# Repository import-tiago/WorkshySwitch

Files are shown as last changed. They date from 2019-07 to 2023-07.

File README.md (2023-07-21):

# WorkshySwitch
 

WorkshySwitch is an IoT device for wireless control of lamps without harming the use of the physical switch.

## Features
##### Controller Device / [SoC CC2541 with 8051 MCU and Embedded Bluetooth 4.0](http://www.ti.com/lit/ds/symlink/cc2541.pdf)

##### Wireless Technology / [Embedded Meandered Inverted F Antenna (MIFA) with 50 ohm at 2.45 GHz](https://github.com/import-tiago/WorkshySwitch/blob/master/Hardware/3.%20Datasheets/MCU/CC25XX%20-%20Small%20Size%202.4%20GHz%20PCB%20antenna.pdf)

##### Low Power Requirements / Does not apply in this project

##### Hardware Project / [Autodesk EAGLE](https://www.autodesk.com/products/eagle/free-download)

##### Firmware Project / [IAR Embedded Workbench](https://www.iar.com/iar-embedded-workbench/)

##### 3D Model Project / [Autodesk Fusion 360](https://www.autodesk.com/products/fusion-360/overview#banner)

## PCB Details
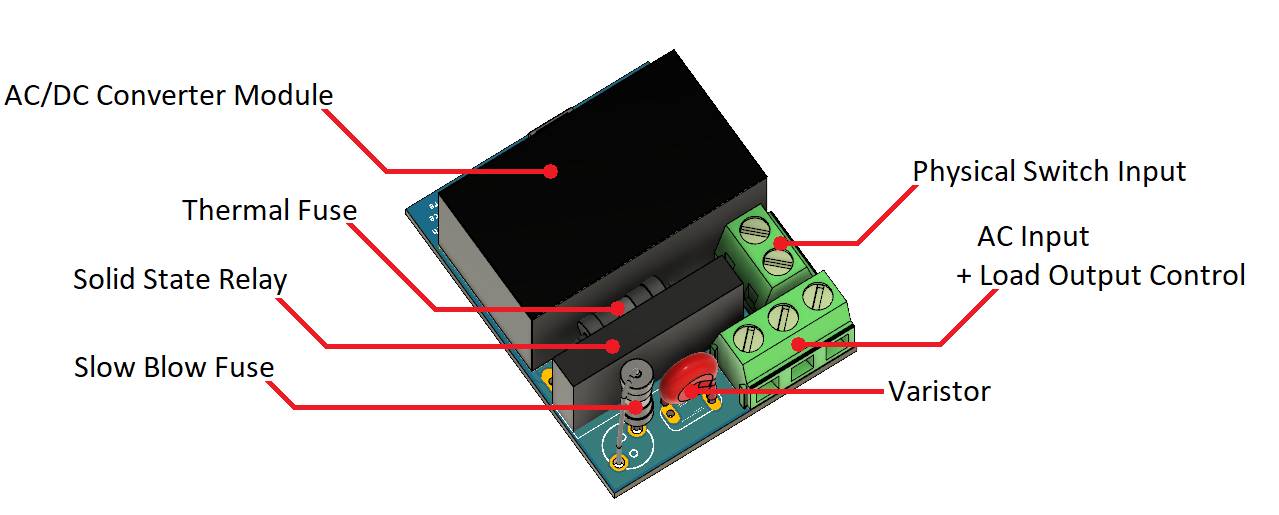
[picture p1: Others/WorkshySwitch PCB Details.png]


## How to Connect
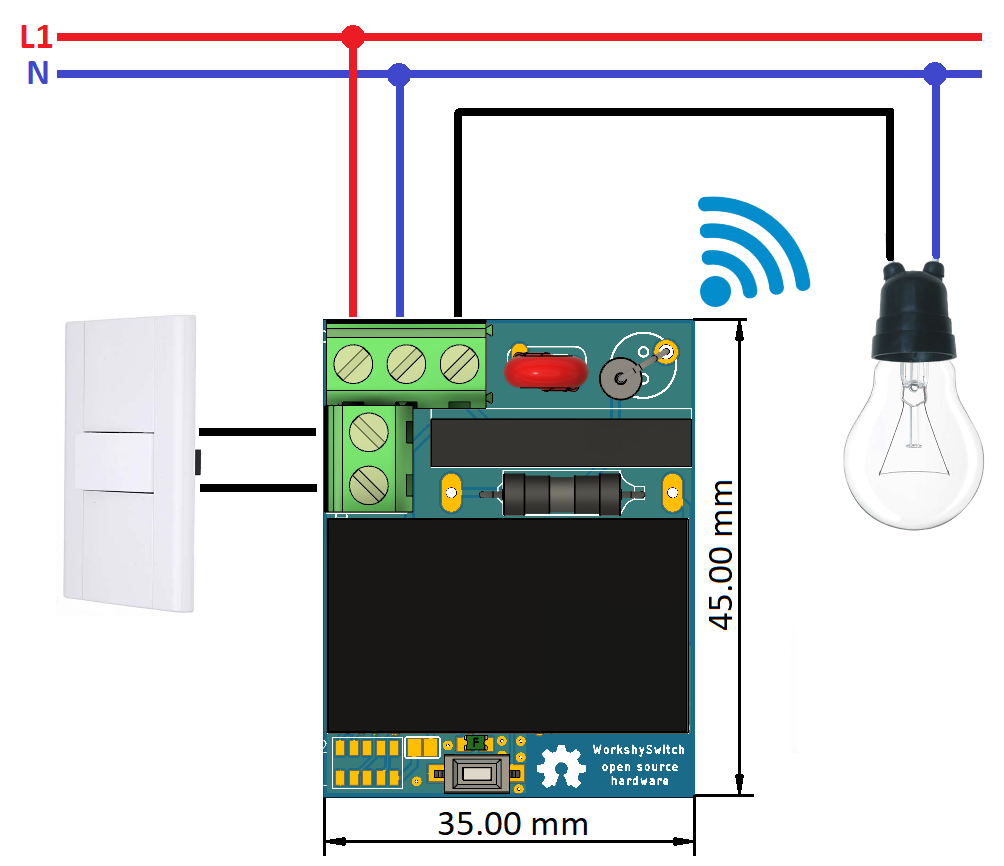
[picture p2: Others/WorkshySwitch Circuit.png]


## Schematic
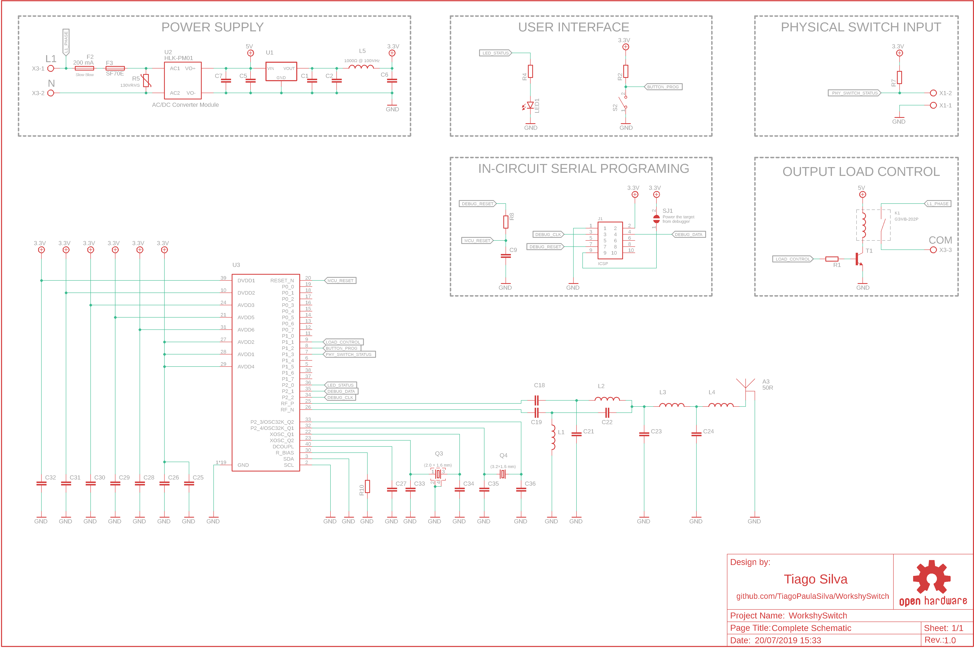
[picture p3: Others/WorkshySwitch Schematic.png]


### Contributing
0. Give this project a :star:
1. Create an issue and describe your idea.
2. [Fork it](https://github.com/import-tiago/WorkshySwitch/fork).
3. Create your feature branch (`git checkout -b my-new-feature`).
4. Commit your changes (`git commit -a -m "Added feature title"`).
5. Publish the branch (`git push origin my-new-feature`).
6. Create a new pull request.
7. Done! :heavy_check_mark:

### License Information
<br /><span xmlns:dct="http://purl.org/dc/terms/" property="dct:title">WorkshySwitch</span> by <a xmlns:cc="http://creativecommons.org/ns#" href="https://github.com/import-tiago" property="cc:attributionName" rel="cc:attributionURL">Tiago Silva</a> is licensed under a <a rel="license" href="http://creativecommons.org/licenses/by-sa/4.0/">Creative Commons Attribution-ShareAlike 4.0 International License</a>.<br />Permissions beyond the scope of this license may be available at <a xmlns:cc="http://creativecommons.org/ns#" href="https://twitter.com/import_tiago" rel="cc:morePermissions">tiagodepaulasilva@gmail.com</a>.

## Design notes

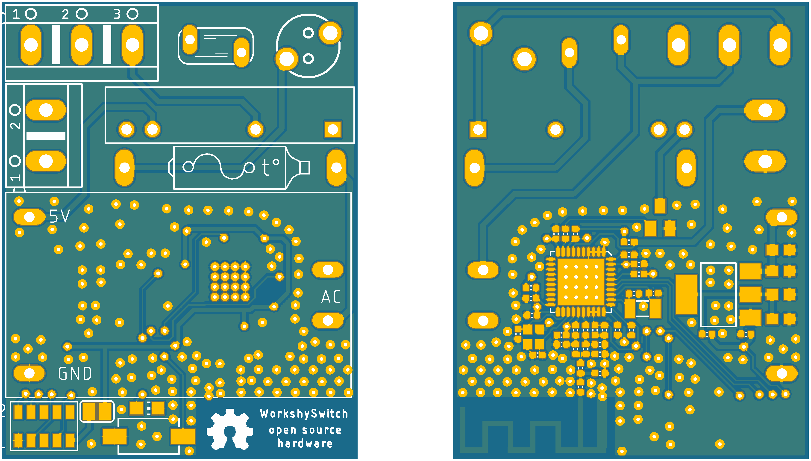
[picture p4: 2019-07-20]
Hardware/1. Mounting/WorkshySwitch.png

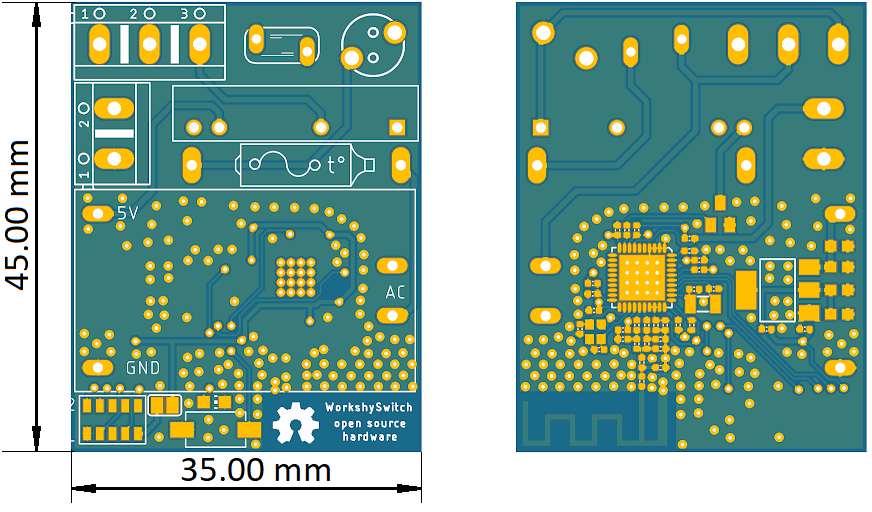
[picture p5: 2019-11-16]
Others/WorkshySwitch Gerber Preview.png

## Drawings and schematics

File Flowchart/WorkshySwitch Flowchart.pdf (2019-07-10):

# START

# WorkshySwitch MCU Firmware

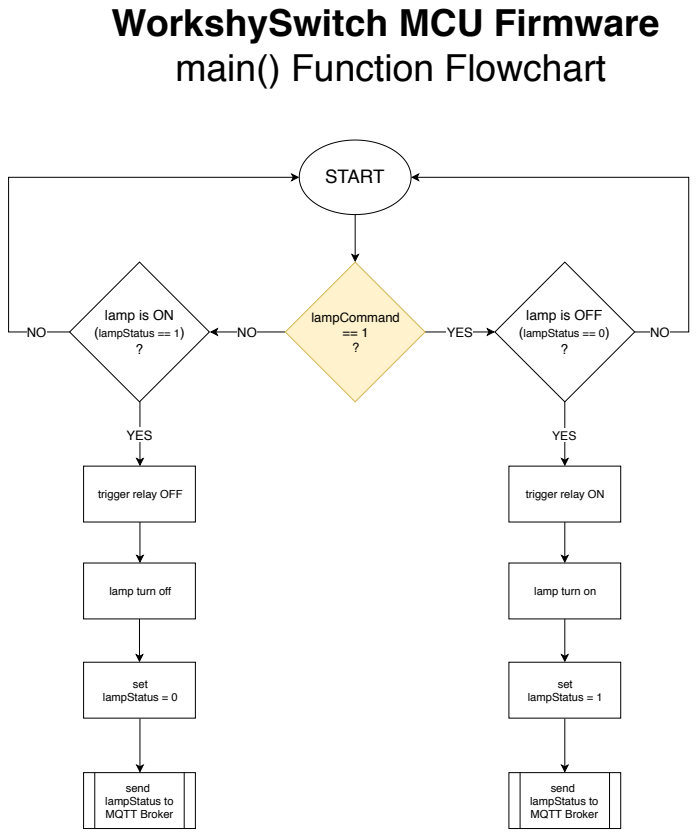
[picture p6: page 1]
set lampStatus = 1; send lampStatus to MQTT Broker; YES; lamp is OFF; (lampStatus == 0) ?; set lampStatus = 0; lamp is ON; (lampStatus == 1) ?; lampCommand == 1 ?

main() Function Flowchart

trigger relay OFF

trigger relay ON

lamp turn off

lamp turn on

# WorkshySwitch MCU Firmware Interrupt Services Routine Flowchart

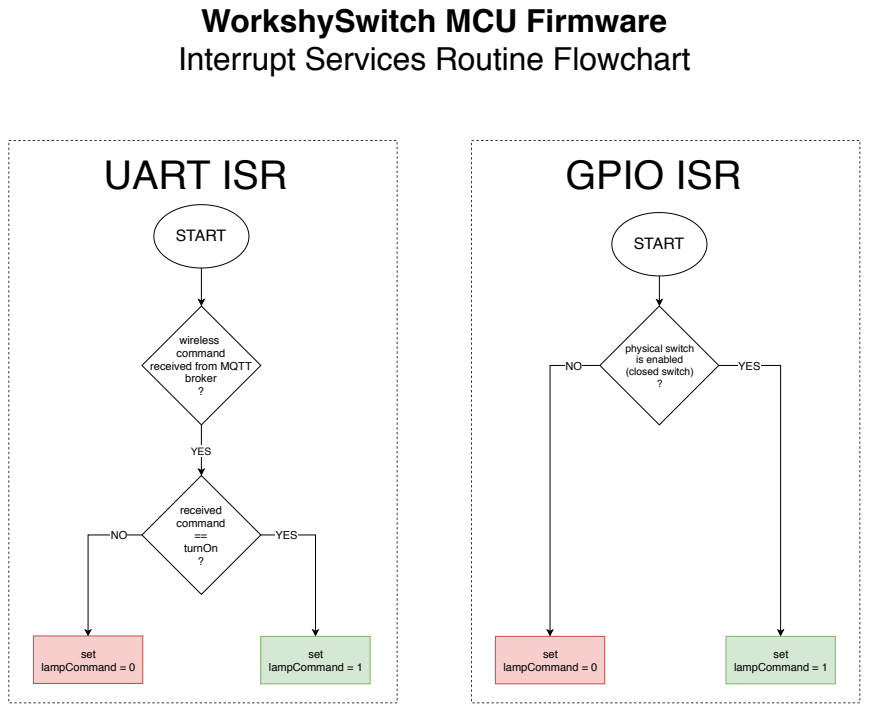
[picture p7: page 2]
START; YES; received command == turnOn ?; broker ?; set lampCommand = 1; physical switch is enabled (closed switch) ?; set lampCommand = 0; UART ISR; GPIO ISR

wireless
command
received from MQTT

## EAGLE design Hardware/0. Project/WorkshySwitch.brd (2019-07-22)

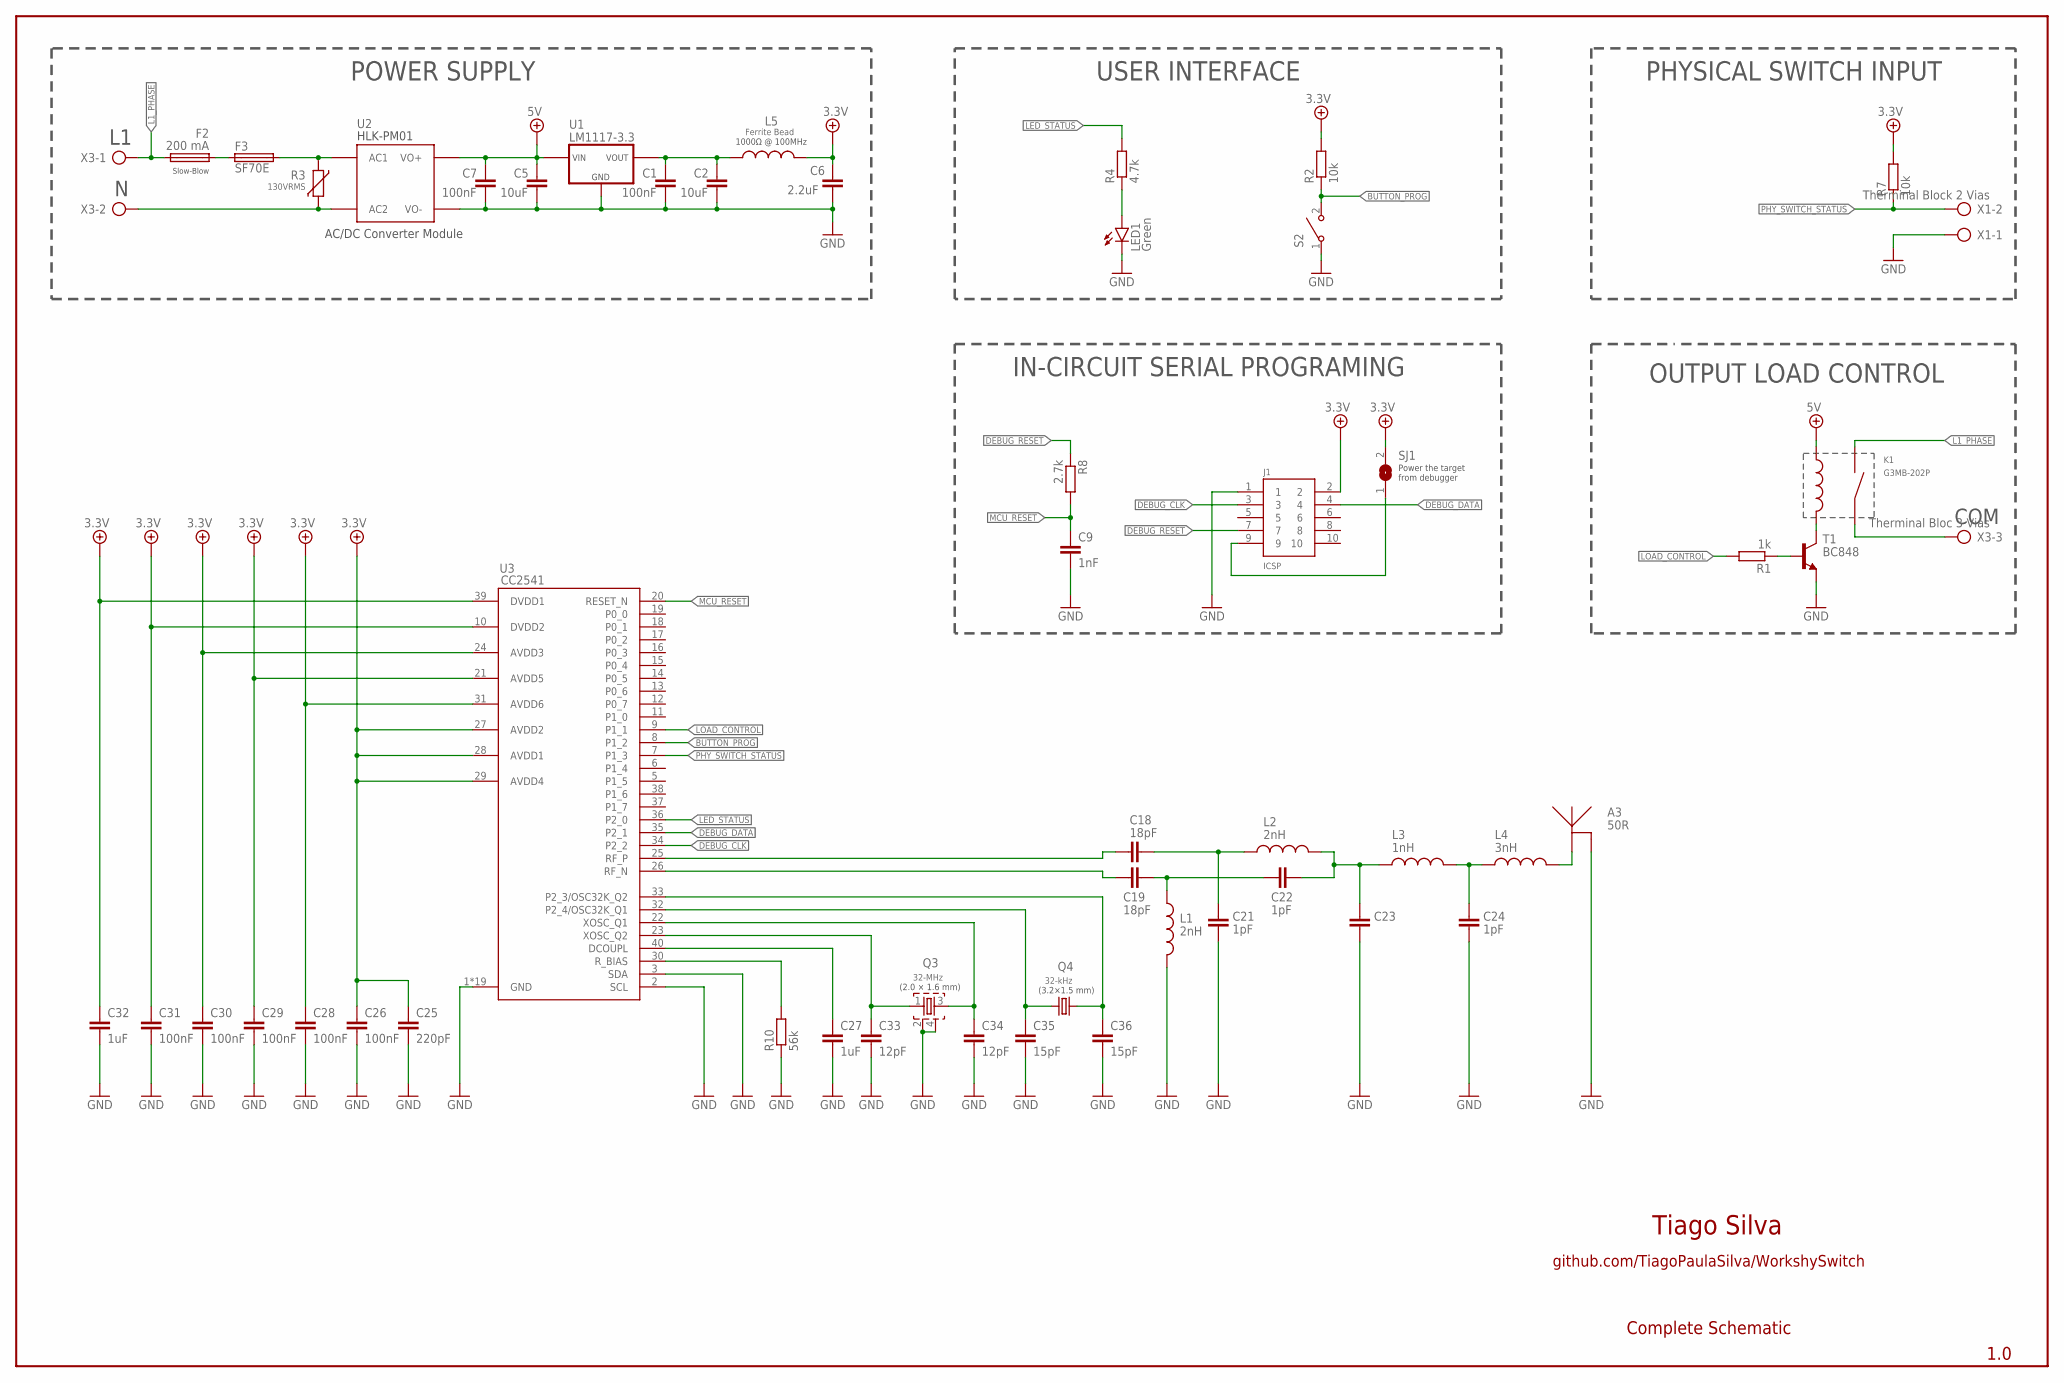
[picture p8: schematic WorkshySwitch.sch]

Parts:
A3: 50R; MIFA
C1, C7: 100nF; C0603
C2, C5: 10uF; C0603
C6: 2.2uF; C0402
C9: 1nF; C0402
C18, C19: 18pF; C0402
C21, C22, C24: 1pF; C0402
C23: C0402
C25: 220pF; C0402
C26, C28, C29, C30, C31: 100nF; C0402
C27, C32: 1uF; C0402
C33, C34: 12pF; C0402
C35, C36: 15pF; C0402
F2: 200 mA; QPL
F3: SF70E; LITTLEFUSE
J1: ICSP; SHF-105-01-X-D-SM
K1: G3MB-202P; RELAY_G3MB202PDC12
L1, L2: 2nH; C0402
L3: 1nH; C0402
L4: 3nH; C0402
L5: Ferrite Bead; C0402
LED1: Green; CHIP-LED0805
Q3: 32-MHz; FA-128
Q4: 32-kHz; 3.2X1.5
R1: 1k; C0402
R2, R7: 10k; C0402
R3: 130VRMS; S05K11
R4: 4.7k; C0402
R8: 2.7k; C0402
R10: 56k; C0402
S2: 434121050816
SJ1: Jumper; SJ
T1: BC848; SOT23
U1: LM1117-3.3; SOT223
U2: HLK-PM01
U3: CC2541; QFN50P600X600X100-41N
X1: Therminal Block 2 Vias; AK500/2
X3: Therminal Bloc 3 Vias; AK500/3

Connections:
3.3: C1.1, C2.1, L5.2, U1.2 (VOUT), U1.4 (VOUT)
3.3V: C6.1, C25.1, C26.1, C28.1, C29.1, C30.1, C31.1, C32.1, J1.2, L5.1, R2.2, R7.2, SJ1.2, U3.10 (DVDD2), U3.21 (AVDD5), U3.24 (AVDD3), U3.27 (AVDD2), U3.28 (AVDD1), U3.29 (AVDD4), U3.31 (AVDD6), U3.39 (DVDD1)
5V: C5.1, C7.1, K1.3 (+), U1.3 (VIN), U2.P$4 (VO+)
BUTTON_PROG: R2.1, S2.2, U3.8 (P1_2)
DEBUG_CLK: J1.3, U3.34 (P2_2)
DEBUG_DATA: J1.4, U3.35 (P2_1)
DEBUG_RESET: J1.7, R8.1
GND: A3.GND, C1.2, C2.2, C5.2, C6.2, C7.2, C9.2, C21.2, C23.1, C24.2, C25.2, C26.2, C27.2, C28.2, C29.2, C30.2, C31.2, C32.2, C33.2, C34.2, C35.2, C36.2, J1.1, L1.2, LED1.C, Q3.2, Q3.4, R10.1, S2.1, T1.2 (E), U1.1 (GND), U2.P$3 (VO-), U3.1 (GND), U3.2 (SCL), U3.3 (SDA), U3.4 (GND), U3.41 (GND), U3.42 (GND), U3.43 (GND), U3.44 (GND), U3.45 (GND), U3.46 (GND), U3.47 (GND), U3.48 (GND), U3.49 (GND), U3.50 (GND), U3.51 (GND), U3.52 (GND), U3.53 (GND), U3.54 (GND), U3.55 (GND), U3.56 (GND), U3.57 (GND), X1.1
L1_PHASE: F2.2, K1.1 (L1), X3.1
LED_STATUS: R4.2, U3.36 (P2_0)
LOAD_CONTROL: R1.2, U3.9 (P1_1)
MCU_RESET: C9.1, R8.2, U3.20 (RESET_N)
unnamed: LED1.A, R4.1
unnamed: R3.2, U2.P$2 (AC2), X3.2
unnamed: F3.2, R3.1, U2.P$1 (AC1)
unnamed: K1.4 (-), T1.3 (C)
unnamed: R1.1, T1.1 (B)
unnamed: K1.2 (L2), X3.3
unnamed: F2.1, F3.1
unnamed: J1.9, SJ1.1
unnamed: C18.1, U3.25 (RF_P)
unnamed: C19.1, C22.2, L1.1
unnamed: C22.1, C23.2, L2.2, L3.1
unnamed: C19.2, U3.26 (RF_N)
unnamed: C18.2, C21.1, L2.1
unnamed: C24.1, L3.2, L4.1
unnamed: A3.FEED, L4.2
unnamed: C27.1, U3.40 (DCOUPL)
unnamed: R10.2, U3.30 (R_BIAS)
unnamed: C33.1, Q3.1, U3.23 (XOSC_Q2)
unnamed: C34.1, Q3.3, U3.22 (XOSC_Q1)
unnamed: C35.1, Q4.1, U3.32 (P2_4/OSC32K_Q1)
unnamed: C36.1, Q4.2, U3.33 (P2_3/OSC32K_Q2)
PHY_SWITCH_STATUS: R7.1, U3.7 (P1_3), X1.2

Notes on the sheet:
Tiago Silva
github.com/TiagoPaulaSilva/WorkshySwitch
1.0
Complete Schematic
AC/DC Converter Module
POWER SUPPLY
PHYSICAL SWITCH INPUT
OUTPUT LOAD CONTROL
COM
Slow-Blow
(3.2×1.5 mm)
(2.0 × 1.6 mm)
1000Ω @ 100MHz
Power the target from debugger
USER INTERFACE
IN-CIRCUIT SERIAL PROGRAMING

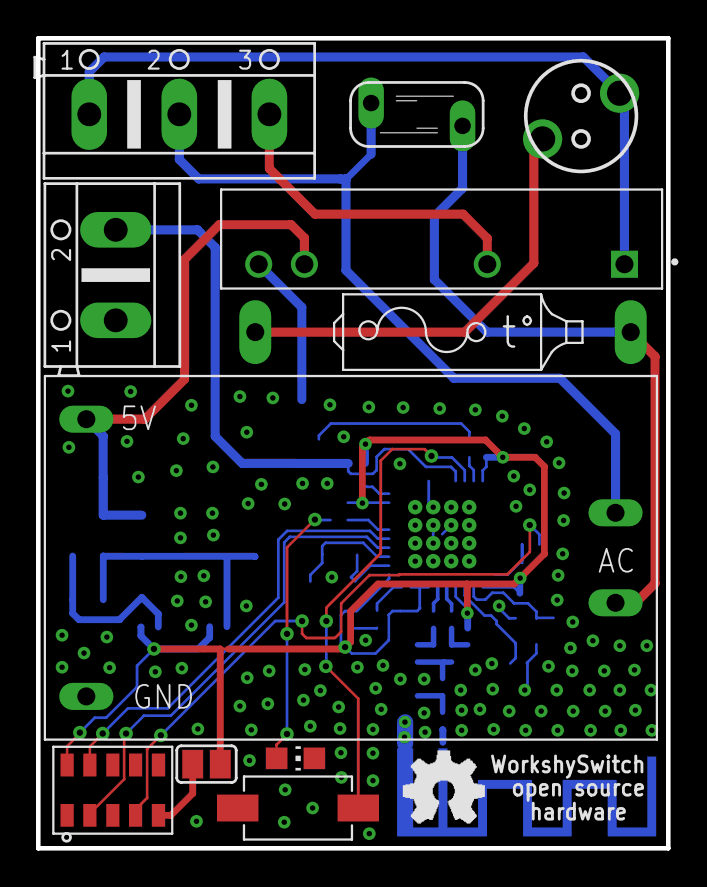
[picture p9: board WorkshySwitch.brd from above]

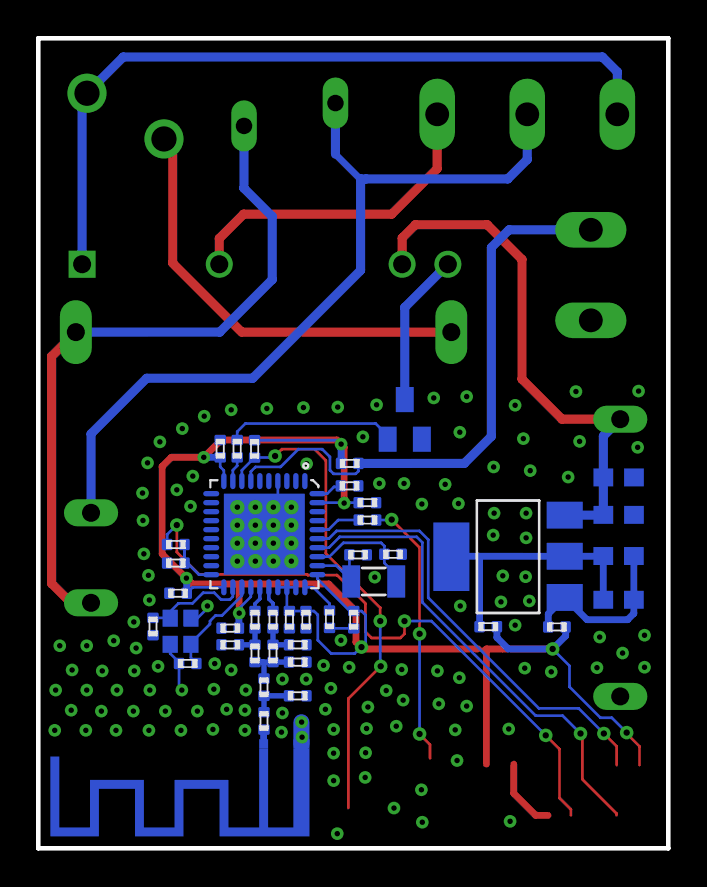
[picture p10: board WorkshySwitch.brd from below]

Board: 2 copper layers, 35.0 x 45.0 mm, 52 parts (41 on the bottom side), 34 nets.

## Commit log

2019-07-10 Protect circuit added
    [WorkshySwitch.brd, WorkshySwitch.sch]
2019-07-10 PCB layout under dev
    [WorkshySwitch.brd, WorkshySwitch.sch]
2019-07-10 Flowchart added
2019-07-17 New hardware design approch
    - The previous approach would be too large.
    - Now, MCU and BLE module don't exists anymore.
    - A new MCU with embedded BLE was added: CC2541.
    [WorkshySwitch.brd, WorkshySwitch.sch]
2019-07-17 Reduced number of PTR connectors
    [WorkshySwitch.brd, WorkshySwitch.sch]
2019-07-20 PCB layout done
    [WorkshySwitch.brd, WorkshySwitch.sch]
2019-07-20 Gerbers files generated
    [WorkshySwitch.brd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]
2019-07-20 3D PCB Model Generated
    [WorkshySwitch.brd, WorkshySwitch.sch]
2019-07-20 Components values added
    [WorkshySwitch.brd, WorkshySwitch.sch]
2019-07-21 Gerber files updated
    [WorkshySwitch.brd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]
2019-07-22 Width of top polygon increased
    [WorkshySwitch.brd]
2019-07-22 Minor improvement in the TOP layer
    [WorkshySwitch.brd]

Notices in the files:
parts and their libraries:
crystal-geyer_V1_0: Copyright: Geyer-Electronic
